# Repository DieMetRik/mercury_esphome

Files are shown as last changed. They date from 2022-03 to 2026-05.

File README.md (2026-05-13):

# Меркурий 206 <-> ESP8266 <-> Home Assistant

## Обновление от 13.05.2026

Добавлен модуль в виде external_component для совместимости с 2025.2+
Пока тестировался на 2025.11
---------------------------------------------------------------------------------

disclaimer:
Сразу скажу, что я не проф. программист, поэтому код может где то быть не элегантен.

За основу взят проект https://github.com/RocketFox2409/MercuryESPHome

И так, была задача передавать показания со счетчика Меркурий 206 (RS-485) в Home Assistant. 

Изначально провод от счетчика шел через преобразователь USB-RS485 в сервер HomeAssistant на Raspberry и через Node-Red формировался запрос и принимался ответ. Все работало, но пришло время развиваться и убрать лишние провода. 

Было собрано 3 сетапа:

1. Первый сетап: Wemos D1 mini + RS485 (MAX485 chipset) + DC-DC конвертер для стабильного питания.
   Работает, но очень не стабильно, постоянно отваливается Wemos.
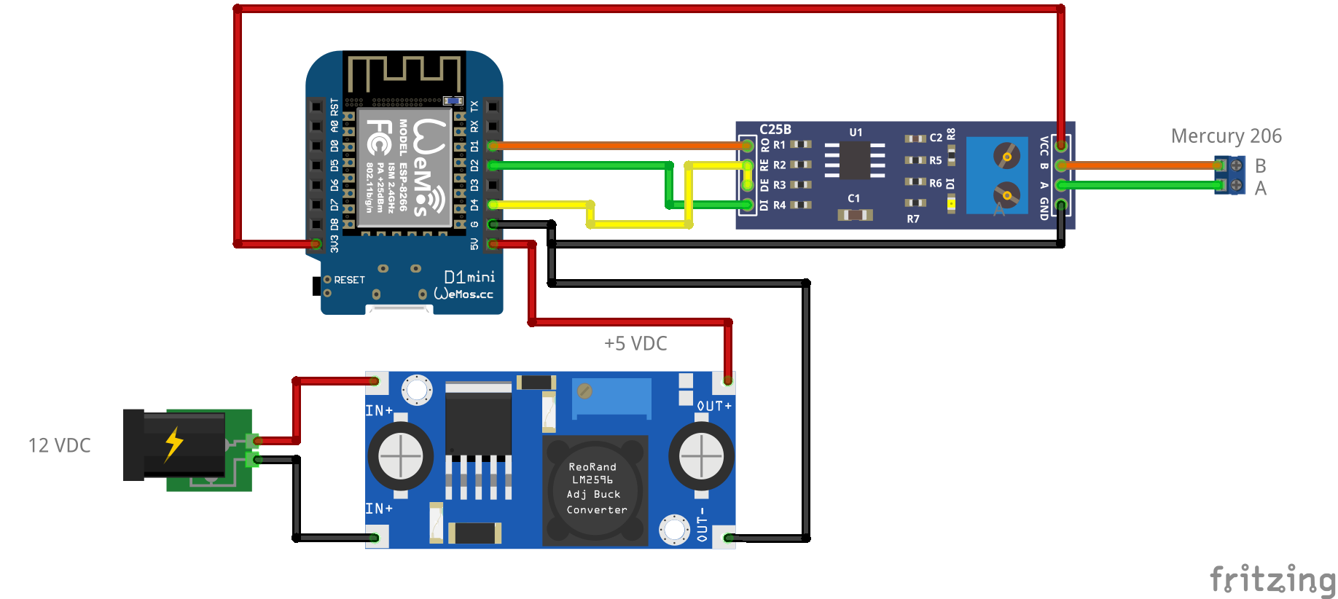
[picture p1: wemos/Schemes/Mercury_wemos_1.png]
   
2. Во втором сетапе добавил дополнительный DС-DC для питания модуля RS485
   Стало постабильнее, но все равно отваливается, так как в Wemos использовал SoftwareSerial, думаю дело в этом
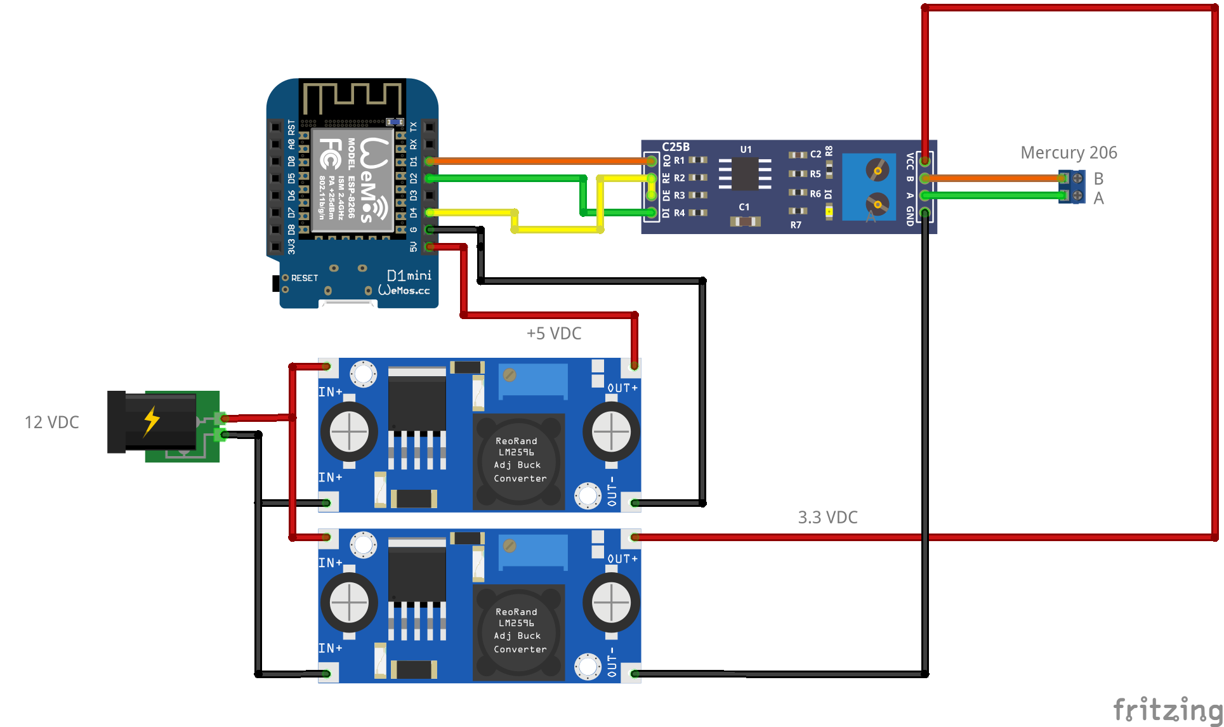
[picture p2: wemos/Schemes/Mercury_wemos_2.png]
   
3. Третий сетап аналогичен второму, только Wemos заменил на ESP-01s с HardwareSerial, работает стабильно. Больше трогать не буду.
   Если будут проблемы, можно еще попробовать Wemos с HardwareSerial (пока не изучал вопрос).
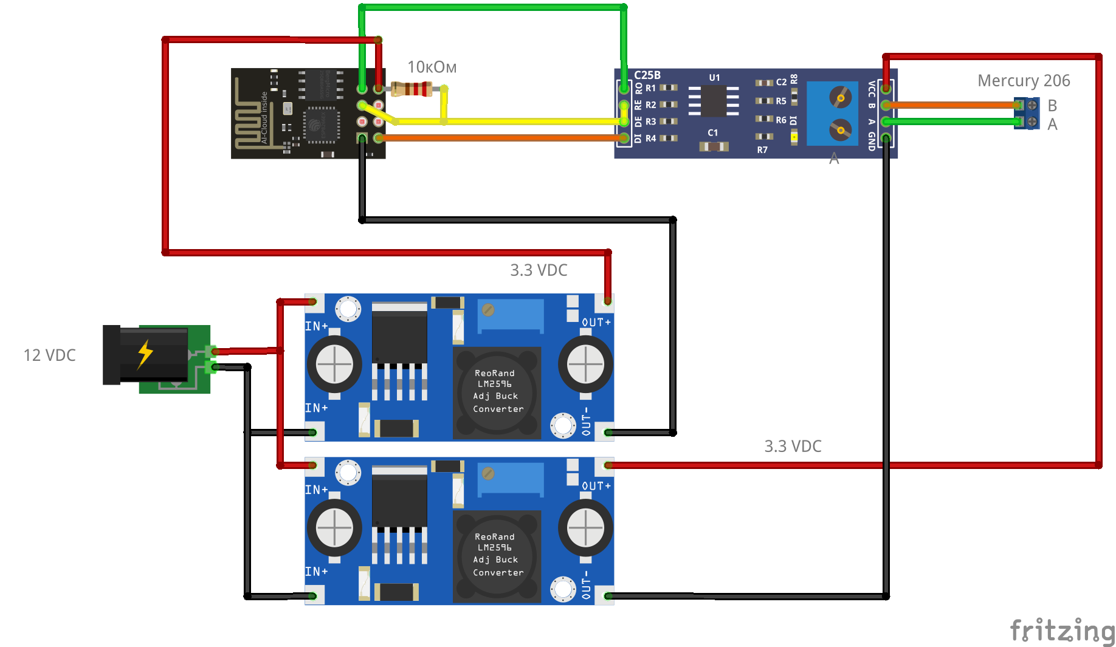
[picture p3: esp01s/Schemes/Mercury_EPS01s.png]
   
4. Купил новую плату для Modbus https://aliexpress.ru/item/32817720482.html c ней стало намного проще работать. Рекомендую именно ее.
   Там все просто:
   - 3.3 <-> VCC 
   - RX <-> RX
   - TX <-> TX
   - GND <-> GND
   В этой плате не нужно подавать дополнительно сигнал на чтение\запись, что упрощает и сборку и код
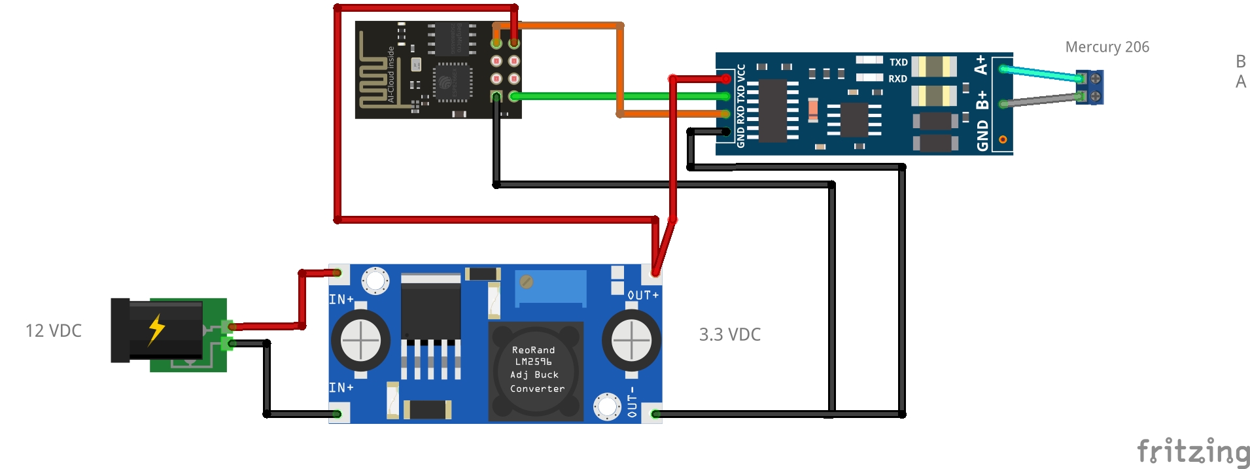
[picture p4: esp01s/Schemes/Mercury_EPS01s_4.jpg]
   
   
Для соответствующего сетапа потребуется:
Скопировать 2 файла в /config/esphome/mercury/
- mercury-200.02.h
- sensor.py

Сожержимое yaml файла скопировать в свой проект в ESPHome 
Поменять адресс счетчика в файле "mercury-200.02.h"

В Home Assistant сделал вот так:
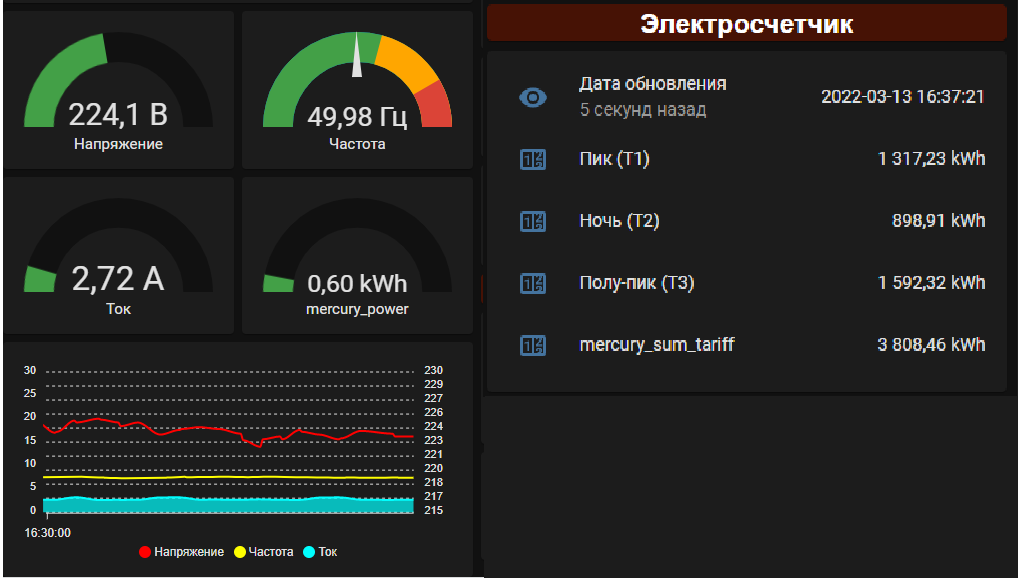
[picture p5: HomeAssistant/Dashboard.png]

Прокинул все в Energy Management и получилось вот так:
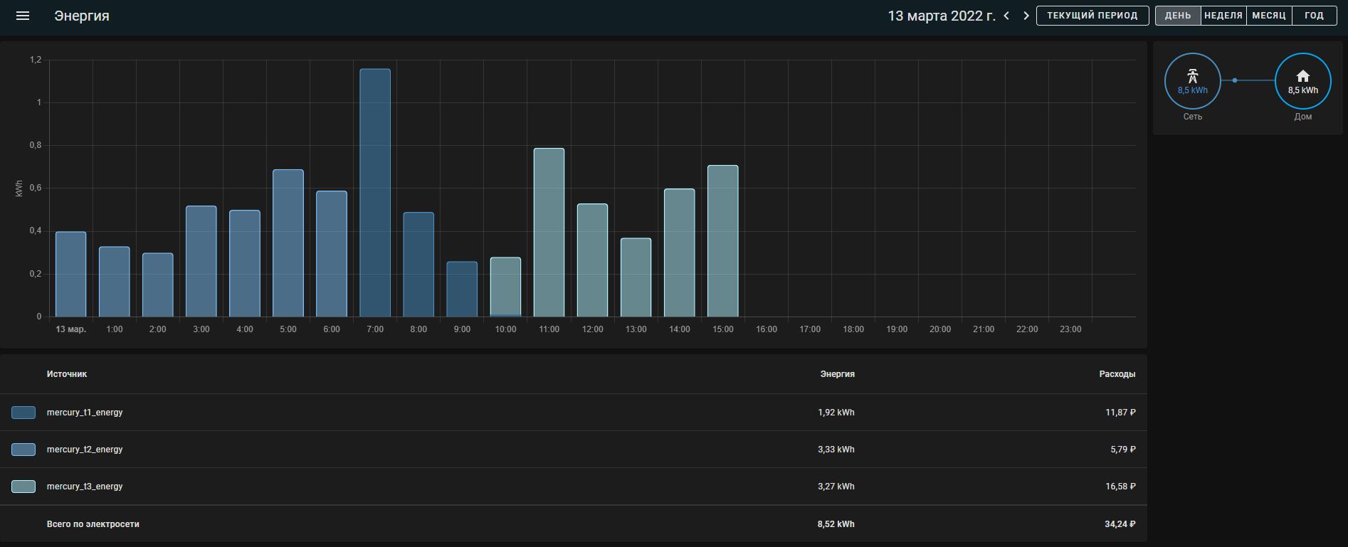
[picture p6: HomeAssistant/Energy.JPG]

Цены по тарифам взял из интеграции "Личный кабинет Интер РАО"

настроил отправку показаний в Энергосбыт через интеграцию "Личный кабинет Интер РАО" (устанавливается через HACS) + Node-Red для формирования данных.

Оборудование:

ESP01s заказывал у Win Win с Алика https://aliexpress.ru/item/2037396994.html
Для ESP01s первый раз нужен программатор, я использовал: https://aliexpress.ru/item/32688280601.html
Нужно сделать 2 перемычки:
GND + IO0
3.3V + EN
Я припаял 8 pin к программатору с другой сторны и просто сделал перемычками. Получилось универсально.

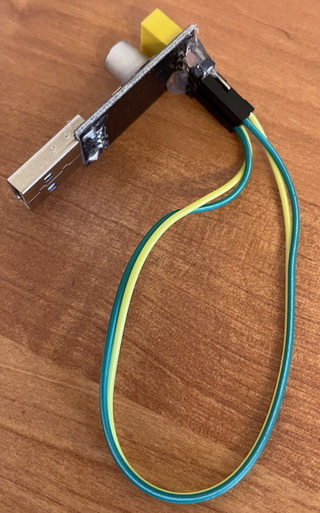
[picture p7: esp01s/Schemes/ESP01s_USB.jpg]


Wemos D1 mini V3.0.0 там же https://aliexpress.ru/item/32651747570.html

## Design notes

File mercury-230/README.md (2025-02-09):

# Меркурий 230 <-> 485 <-> ESP32 <-> Home Assistant

Автор кода https://github.com/Brokly/ESPHome-Mercury230

Я просто добавил возможность просмотра тарифов по 3м фазам Активная и Реактивная энергия.

Все что вы делаете, вы делаете на свой страх и риск. 

Вы должны понимать, что вы делаете и к чему это может привести.

Автор скриншотов: https://github.com/BoskSpb



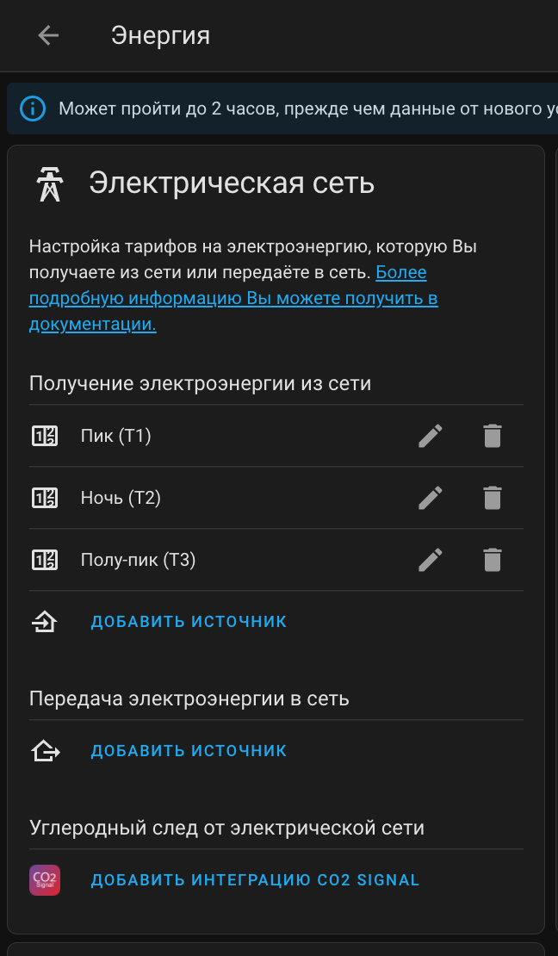
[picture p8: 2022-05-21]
HomeAssistant/Energy_1.png

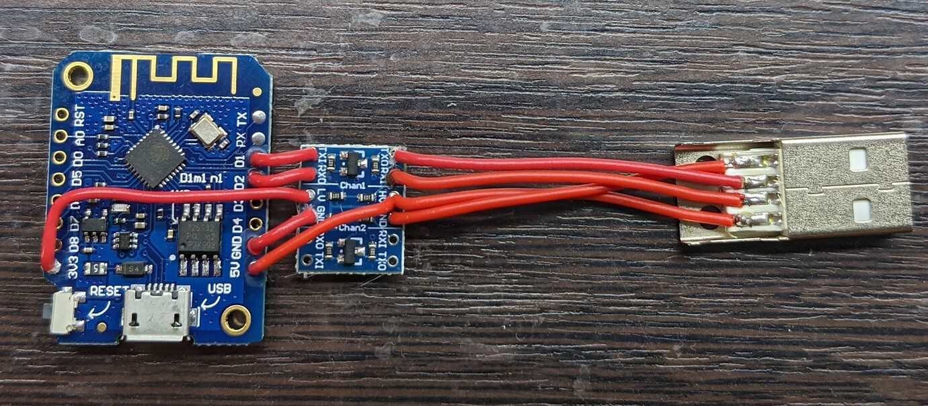
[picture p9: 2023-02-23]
wemos/Schemes/Level.png

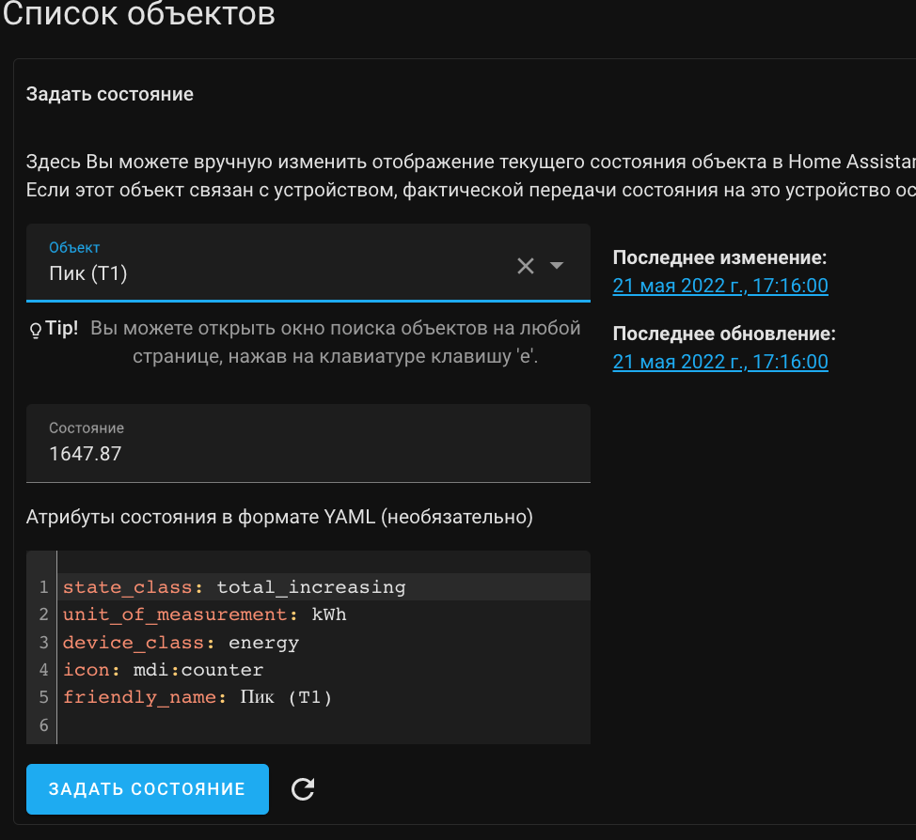
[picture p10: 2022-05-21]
HomeAssistant/Energy_4.png

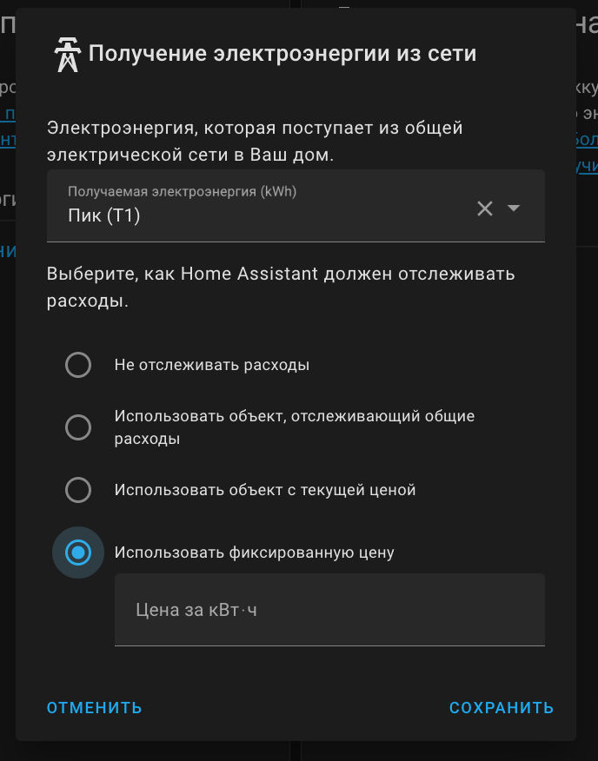
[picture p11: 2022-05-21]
HomeAssistant/Energy_3.png

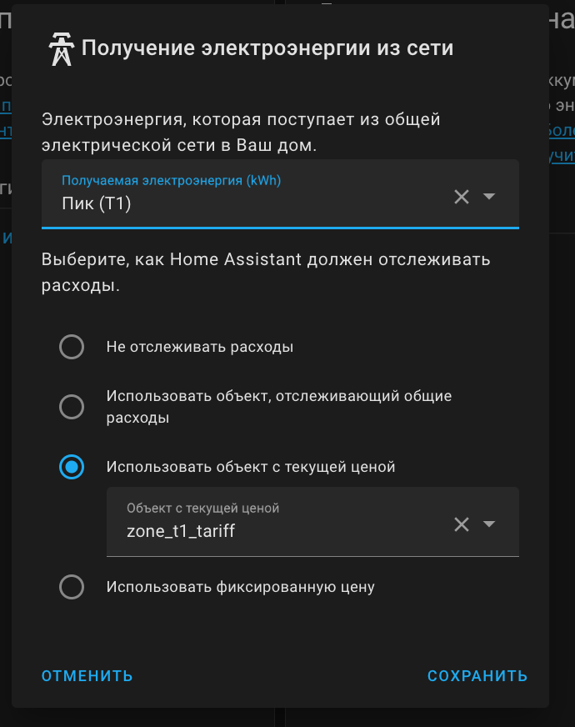
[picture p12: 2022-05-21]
HomeAssistant/Energy_2.png

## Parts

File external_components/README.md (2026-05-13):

# Меркурий 206 <-> ESP32 ethernet <-> Home Assistant
disclaimer:
Сразу скажу, что я не проф. программист, поэтому код может где то быть не элегантен.

За основу взят проект https://github.com/RocketFox2409/MercuryESPHome

Переделал проект из  custom_component --> external_component

Плата ESP32 с Ethernet на борту, самый стабильный вариант!

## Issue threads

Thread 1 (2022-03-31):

Прошу помощи.

meta11st87, 2022-03-31:
Приветствую. Спасибо за инфу по подключению.
Пытаюсь повторить ваше проект, но маленько на другом железе и ничего не выходит(

Использую плату nodemcu esp32(потому что была в наличии) и плату ttl rs485, вроде как называется XY-017
Управление потоком аппаратное, поэтому вроде как не нужно ничего на плату подключать, кроме rt/tx и питания.
Схема подключения:
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

Конфиг до раздела сенсоров:
```
esphome:
  name: mercury
  includes:
    - /config/esphome/mercury/mercury-200.02.h #Указываем свой путь до файла

esp32:
  board: nodemcu-32s
  framework:
    type: arduino

# Enable logging
logger:

# Enable Home Assistant API
api:
  password: !secret ha_password

ota:
  password: !secret ota_password

wifi:
  ssid: !secret wifi_ssid
  password: !secret wifi_password

  # Optional manual IP
  manual_ip:
    static_ip: 192.168.1.150
    gateway: 192.168.1.1
    subnet: 255.255.255.0

  # Enable fallback hotspot (captive portal) in case wifi connection fails
  ap:
    ssid: "mercury-206"
    password: !secret ap_password

captive_portal:

uart:
  id: uart_bus
  tx_pin: 17
  rx_pin: 16
  baud_rate: 9600
```

Тх моргают, но счётчик не отвечает, рх молчит. Плату запитывал тестово от повербанка.
Собственно, ряд вопросов:
У вас какой модификации счётчик? У меня RN, вроде как они отличаются, что какому-то счётчику нужно доппитание, а какому-то нет.

Адрес счётчика как правильно выставить? У меня номер счётчика 12343320 -18. Если ставлю 320 то результата положительного нет. Вроде как эти счётчики должны на 0 адрес отвечать, если в шине он один, но это тоже не работает.

Вроде все варианты уже перепробовал, но не взлетает.

Может у вас есть мысли ЧЯДНТ?

upd. Пробовал на контакты счётчика, которые рядом с rs расположены, и которые промаркированы как U и земля, подать 5в, судя по той инфе, которая нашлась в интернете это питание rs-интерфейса - не помогло.

DieMetRik, 2022-04-01:
Для начала.
Счётчик новый?
В него могли записать другой адрес?

У меня просто в счётчик местный энергосбыт записал номер квартиры как адрес счётчика. Поэтому там указано 319. Хотя по факту там должен был быть его серийный номер без нолей вначале и без тире в конце. Если в ваш счётчик никто не залезал, кроме Вас, то в поле адреса нужно вписать: 12343320

Пробовали менять провода А и В местами?

Есть ли у Вас преобразователь USB-RS485? Стоил раньше в районе 100р +-
С ним диагностика вопроса была бы намного проще.

Можно было бы подключится к счётчику прям с ноутбука и проверить, есть ли вообще связь. Есть специальная программа для счётчиков Меркурий от самого Маркурия.

Перед всей своей эпопеей со счётчиком, я сначала подключился ей и проверил, что счётчик отзывается.
Потом уже подключался с помощью ESP

Ещё можно поиграться с временем delay вот в этой части кода:

```
		digitalWrite(0, HIGH);
		write_array(command, 7);
		delay(12);
		digitalWrite(0, LOW);
		//delay(13);
```

В Вашем случаи вообще нужно будет закоментить: digitalWrite(0, HIGH); digitalWrite(0, LOW); так как у Вас нормальный преобразователь. А с delay можно поиграться.

У меня было такое что, при малом delay порт ESP не успевал передать все данные и данные уходили урезанные.

Все это я диагностировал с помощью USB to RS485 преобразователя. С него же и подключался к счётчику через ноут.
`https://aliexpress.ru/item/1005003203376943.html?`

Если у Вас счётчик без буковки S, то ему нужно внешнее питание +5V.  при этом GND я так понял должны быть соединены. Опять же это не точно. Нужно смотреть схему подключения.

DJTerentjev, 2022-04-01:
У китайских плат часто перепутано RX и TX, но если TX моргает значит, вроде правильно. Похоже у вас адрес счётчика неправильно указан. Я когда подключал, сначала подключался к счётчику утилитой Меркурия через переходник RS-485-USB.  Номер по умолчанию, должен быть указан в мануале. Если правильно помню, должен быть 80 или 64 (перевести в hex).

DieMetRik, 2022-04-01:
Надо смотреть какой Меркурий. Там для разных меркуриев и по разному задаёте адрес. Для 206 это серийник

meta11st87, 2022-04-01:
>
Благодарю за ответ.
Счётчику год, похоже, надо сначала usb -> rs485 опросить, может действительно поменян адрес.
Жаль что по месту их не найти в городе.

Но и адрес правильно я не указал(пробовал по разному, хотя мне вообще казалось что в таких устройствах адрес не может быть больше 255), может ночью потестирую ещё.

А В не менял местами, вроде судя по описанию интерфейса rs485 они должны подключаться напрямую.

С delay эксперементировать в сторону увеличения, я правильно понял?

meta11st87, 2022-04-01:
> У китайских плат часто перепутано RX и TX. Я использую XY-017 и подключаю TX к TX, RX к RX. Если TX моргает значит, вроде правильно. Похоже у вас адрес счётчика неправильно указан. Я когда подключал, сначала подключался к счётчику утилитой Меркурия через переходник RS-485-USB. Номер по умолчанию, должен быть указан в мануале. Если правильно помню, должен быть 80 или 64 (перевести в hex).

Да, я видел эту инфу в интернете, пробовал tx rx менять местами.
В итоге пришёл к тому, что если моргает tx, значит подключение правильное в этой части схемы.

DieMetRik, 2022-04-01:
Это не модбас. Поэтому адрес может быть любой. Выводы A и B каждый по разному может делать. Так что тут только поменять и попробовать.
Делай увеличить надо попробовать.

AntoxaSa, 2022-04-29:
Добрый день!
Хочу тоже счет прокинуть в HA.
Встал выбор какой лучше купить меркурий 200.02 или 206? чем они отличаются?

DieMetRik, 2022-04-29:
Добрый день!
200.02 не имеет RS-485 интерфейса
Для 206 есть RS-485. У меня Меркурий 206 PRSN Отлично справляется со своими делами

AntoxaSa, 2022-04-29:
а принципиальная разница какая? 200 же вроде с кан и так же прокидывается в HA ?

AntoxaSa, 2022-04-29:
Заказал как у Вас счетчик,нашел за адекватную цену. 206 PRSN.Подскажите еще где покупали преобразователь TTL RS485 и какой

DieMetRik, 2022-05-08:
Купил новую плату для Modbus https://aliexpress.ru/item/32817720482.html c ней стало намного проще работать. Рекомендую именно ее.
   Там все просто:
   - 3.3 <-> VCC
   - RX <-> RX
   - TX <-> TX
   - GND <-> GND

AntoxaSa, 2022-05-09:
> DieMetRik

а для этой платы Modbus https://aliexpress.ru/item/32817720482.html  в коде Вашей программы что то менять нужно?

DieMetRik, 2022-05-09:
По большому счету нет. Можно закоментировать все строки:
191, 192, 199, 201, 202
А можно и не комментировать. На работоспособность ни как не влияют

vickkz, 2022-05-14:
День добрый,тоже такая же кака,пробовал и таким и таким конвертером, тх моргает, через юсб в РС 485 меркуриевской прогой цепляется нормально и подключается,а через есп не хотит( делей увеличивал, тоже самое,а какой прогой вы диагностировали проблемы и опрашивали счётчик?

DieMetRik, 2022-05-14:
Адрес правильно выставили? Там вместо 319 нужно выставить тот. Который вы выставляли в проге Меркурия.

Попробуйте поменять A и B провода местами.

Если это не поможет. Напишите. Я скажу как диагностировал запросы.

AntoxaSa, 2022-05-18:
Собрал устройство.Прошил, Моргает TX на плате и все но счетчик данные не передает.В Home Asisstent пишет неизвестные данные.A и B перекидывал местами.  Оригинальный серийный номер счетчика состоит из 8 цифр может в этом проблема? Попробовал через USB RS485 и программу конфигуратор все работает. Есть мысли?

AntoxaSa, 2022-05-18:
Вообщем разобрался.Если в счетчике серийный номер из 8 цифр то программа не работает.Видать не может пересчитать серийный номер правильно конвертор.Меняем в счетчике серийный номер на 6 цифр и вауля все работает! HA видит счетчик

vickkz, 2022-05-19:
Спасибо автору за консультацию,тоже удалось завести счётчик через есп,пришлось подредактировать код и стартовый байт поменять в строке запроса авторизации и в строках запроса,потом блудняк был когда рх и тх подключал непосредственно к есп,не работал рх,потом подключил как в скетче и все пошло моргать

meta11st87, 2022-05-19:
.

> есп,пришлось подредактировать код

Выложите свою версию для людей, пожалуйста. И какой счётчик использовали, его конфигурацию(P,R,S,N)

Я всё до дому никак не доеду, чтоб свой счётчик потестировать

vickkz, 2022-05-19:
Счётчик 206 PR без собственного питания,подал 12 в от внешнего источника питания,номер счётчика надо перевести в шеснадцатиричном систему из десятичной,проверил через USB -rs485 правильно ли есп посылает запрос авторизации.

AntoxaSa, 2022-05-19:
> Спасибо автору за консультацию,тоже удалось завести счётчик через есп,пришлось подредактировать код и стартовый байт поменять в строке запроса авторизации и в строках запроса,потом блудняк был когда рх и тх подключал непосредственно к есп,не работал рх,потом подключил как в скетче и все пошло моргать

Выложите код, тоже интересно. для чего правили.

AntoxaSa, 2022-05-19:
> Счётчик 206 PR без собственного питания,подал 12 в от внешнего источника питания,номер счётчика надо перевести в шеснадцатиричном систему из десятичной,проверил через USB -rs485 правильно ли есп посылает запрос авторизации.

не очень понял, для чего переводить? вроде конвертор встроенный в код уже

meta11st87, 2022-05-19:
Итак. Спустя столько времени добрался до счётчика.
Похоже, совет про "сменить номер счётчика" работает с 206rn.
Usb<->RS485 у меня не было, поэтому я взял обычный ttl конвертер для прошивки esp, соединил его с тем самым модулем, через который я пытался опросить счётчик:
rx->rx
tx->tx
vcc->vcc
gnd->gnd,
Вбил номер счётчика по паспорту и сразу же считал данные с него.
Сменил адрес на трёхзначный, опросил уже по новому адресу и проверил что адрес сменился.

А далее всё как в доке написано, сразу заработало.

Но. Я не увидел данные по тариф 1, тариф 2. Правда опрашивал я его через esp не долго, буквально минуту, ибо теперь надо согласовать подключение этой штуки с УК, без электрика наверно не стоит такое делать, счётчик в общем коридоре.
Скрин данных, которые я успел получить. Может данные по тарифам подтягиваются не сразу а раз в определённое время?

А,нет. Скрина не будет. Не знаю как тут картинку запостить. Рукалицо.

vickkz, 2022-05-19:
> Выложите код, тоже интересно. для чего правили.
ну в общем с начальным кодом было так, номер счетчика неверно передавался за счет того,что в коде жестко прописаны стартовые байты 00, а чтобы мой счётчик завелся нужно было 02
пришлось поменять в строках отвечающих за авторизации и за передачу данных 00 на 02
`	void calculateParams(unsigned char *frame, uint32_t serial_, unsigned char comm)
	{
		frame[0] = 0x02;
		frame[1] = serial_ >> 16;
		frame[2] = serial_ >> 8;
		frame[3] = serial_;`
<a href="https://yapx.ru/v/SB25z" title="Фотография загружена на фотохостинг yapx.ru">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</a>

DieMetRik, 2022-05-19:
Всем привет. Сегодня попробую наваять правильный код для 8 цифр серийного номера.
Пока не правильно рассчитываться CRC сумма. Но думаю добью.

Тарифы получаются не сразу...У них период обновления около 10 минут... + еще время на корректное CRC при получении пакета. Иногда требуется 3-4 часпроса.

DieMetRik, 2022-05-20:
Я поправил...Если кто сможет протестировать с длиной серийного номера 8 цифр

AntoxaSa, 2022-05-20:
> Я поправил...Если кто сможет протестировать с длиной серийного номера 8 цифр
Протестирую сегодня.

DieMetRik, 2022-05-21:
Подкорректировал код. Проверьте пожалуйста. Сейчас входные сообщения должны прилетать в HA

AntoxaSa, 2022-05-21:
> Подкорректировал код. Проверьте пожалуйста. Сейчас входные сообщения должны прилетать в HA

Все отлично работает! Еще вопрос а что за сенсор mercury_crc который пишет неизвестно ?
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

DieMetRik, 2022-05-21:
Это когда то был сенсор отладночный. Надо бы его удалить. А так пока просто деактивировать

meta11st87, 2022-05-22:
Раз у всех всё получилось и заработало, предлагаю:

Во-первых, автору прошивки закрыть этот ишью.

Во-вторых, всех кто воспользовался кодом насыпать автору звёзд в репу и задонатить.

Closed 2022-05-22.

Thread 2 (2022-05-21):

Небольшой вопрос

drronn, 2022-05-21:
Здравствуйте! Занимался подключением счетчика меркурий 200.02 и все закончилось успешно, но на Вашей странице увидел скриншот с пробросом в Energy Management. Не подскажете как Вы это сделали? Сорри если оффтоп - просто на гитхабе нельзя отправлять сообщения в приват. Спасибо!

DieMetRik, 2022-05-21:
Добрый день. Заходите на сервер умного дома. Далее /config/energy
Там добавляете сенсоры с kWh и фиксированную цену за kWh.

Скриншоты в папке /HomeAssistant

DieMetRik, 2022-05-21:
Если все получится. Напишите, я закрою

drronn, 2022-05-22:
Здравствуйте. Посмотрел, /config/energy - такой папки не было. Создал. Я правильно понимаю что в этой папке нужно создать yaml файл и записать туда что то вроде:
template:
  sensor:
    - name: "T1"
      unit_of_measurement: 'kWh'
      device_class: energy
      state_class: measurement
      state: '{{ states.sensor.tariff1.state }}'

?

DieMetRik, 2022-05-22:
Не не. Откройте в браузере. http://[адрес home assistan]/config/energy

DieMetRik, 2022-05-22:
Либо через:
Настройки->панели->Энергия

drronn, 2022-05-22:
Я вывел предварительно пункт энергия в боковую панель, но беда в том что там просто невозможно ничего добавить(на скриншоте) поэтому и подумал надо создавать папку и писать.
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.

Если выбрать использовать фиксированную цену и написать 1 то он также не дает сохранять.

DieMetRik, 2022-05-22:
Вверху нужно выбрать показаня со счетчика kWh

DieMetRik, 2022-05-22:
Покажите мне ваши счетчик
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

DieMetRik, 2022-05-22:
Покажите мне ваши счетчик

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

drronn, 2022-05-22:
А вот дело в том что в верхнем раскрывающемся меню ничего нет. То есть нельзя ничего выбрать.
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
А вообще пока вся конструкция пока выглядит вот так
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
если я Вас правильно понял.
В панели разработчика вот так
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

drronn, 2022-05-22:
После того как отправил понял - надо в атрибуты попробовать дописать чтобы стало как у Вас. Возможно это поможет.

DieMetRik, 2022-05-22:
Да...Именно
Нужно обязательно добавить:
    unit_of_measurement: "kWh"
    device_class: energy
    state_class: total_increasing

drronn, 2022-05-22:
Супер! Все получилось! Тему можно закрывать! Спасибо!

Closed 2022-05-22.

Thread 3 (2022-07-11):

На трёх фазный Меркурий (230-236) можете сделать?

sergeibush, 2022-07-11:

DieMetRik, 2022-07-13:
Добрый день!

Думаю да. Напишите какие данные по 3х фазной сети нужны.

and7ey, 2024-01-24:
Добрый день, меня тоже интересует трехфазный Меркурий. У меня 236 ART-01 PQRS.
Показаний и напряжения на каждой фазе, кажется, должно хватить.

https://wifi-iot.com/p/wiki/238/ru/ - тут есть некое решение, но оно вроде в HA не добавляется.

kirush0280, 2025-02-23:
Тоже интересно, мучаюсь с 236 ART-02 PQRS

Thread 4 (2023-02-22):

Пару вопросов по Меркурий 206

DaN66O, 2023-02-22:
Добрый день.
1. Почему вы пишете что использовали SoftwareSerial на Wemos D1 mini, вроде у вас на картинке есть RX и TX ?
2. Вы устанавливали сопротивление 120 Ом между контактами А и В на счетчике ?
В документации по RS485 пишут :
_По стандарту RS-485 шина должна быть проложена без ответвлений и на концах линии должны
быть терминирующие резисторы (100-120 Ом)._
3. Можно ли плату Modbus питать от 5в ?

DieMetRik, 2023-02-23:
Добрый!
1. С Hardware Serial на Wemos D1 mini не завелось, даже при проставление:
logger:
  baud_rate: 0
Не знаю в чем причина, с Software Serial ESP падала часто, стабильно раз в 2-3 часа перезагружалась.
И это не только со счетчиком, у меня еще стоят кондиционеры с ESP, так вот на одном стояло Hardware, а на втором Software. И вот Software падал...

2. Да, со стороны счетчика.
3. Можно при использовании Шифтера.
4. Это нужно собирать на ESP32. Самый стабильный вариант.

У ESP32 есть 2 Hardware Serial и сейчас у меня собрано именно так.

Стоит ESP32 + Shifter + Uart to 485
Shifter:
https://aliexpress.ru/item/32247463702.html?spm=a2g2w.orderdetail.0.0.78f04aa6T0iH3a&sku_id=12000018838496503
Аккуратно, там 10шт в комплекте...я случайно заказа 30шт так.
Вот пример как подключается Level Shifter:
 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
Тут правда D1 Mini, но на ESP32 тоже самое.

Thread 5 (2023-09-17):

Как выяснить адрес счетчика?

Spirituss, 2023-09-17:
ПОдскажите, как узнать адрес счетчика, который нужно прописать в *.h?
Это серийник или код из модбаса?

DieMetRik, 2023-09-17:
Если никто не вмешивался в счетчик. То последние цифры серийника

Spirituss, 2023-09-17:
Серийник на самом счетчике написан?

DieMetRik, 2023-09-17:
Да

Closed 2023-11-27.

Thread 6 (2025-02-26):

Несколько счетчиков 23*

kirush0280, 2025-02-26:
Добрый день!
А можно как то снимать показания с нескольких счетчиков? Вроде библиотека не предназначена для этого, можете помочь с доработкой?

DieMetRik, 2025-02-26:
Он с одного то снимает с ошибками, а если добавить больше, я боюсь ему конкретно поплохеет

DieMetRik, 2025-02-26:
Цена комплекта на 1 счетчик менее 1000р

kirush0280, 2025-02-26:
Спасибо я вроде реализовал на базе https://github.com/flystyle/Mercury230, пришлось править - мне нужно с 4 снимать, если с одного плохо снимает, какой смысл в 4 комплектах?
Пришлось логику переписать, добавил:
$addresses = [49,50,51,52];
и долблю их по очереди - до тех пор, пока не получу от всех ответ. Если ответа нет после 5 запросов - пропускаем.

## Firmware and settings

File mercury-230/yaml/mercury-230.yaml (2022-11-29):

#Автор кода https://github.com/Brokly/ESPHome-Mercury230
#My telegram https://t.me/DieMetRik

# Подключение ног ESP32
# 
# Обязательный элемент
#  ModBus adapter  https://esphome.io/_images/rs485.jpg
#    tx_pin: GPIO14
#    rx_pin: GPIO27
# Дополнительные элементы, для работы не нужны
#  Led Red:   gpio4
#  Led Blue:  gpio16
#  Button:    gpio32
#  Relay:     gpio13

# Имя устройства
substitutions:
  devicename: mercury-230
  upper_devicename: Mercury-230
  location: В электрощите. # место установки
  device_ip: 192.168.1.132


external_components:
  - source: 
      type: local
      path: my_components     
    components: [ energy_meter_mercury230 ]
    refresh: 0s

esphome:
  name: $devicename
  includes:
    - my_components/energy_meter_mercury230/energy_meter_mercury230.h
    - my_components/energy_meter_mercury230/mercury230_proto.h
  on_boot:
    priority: 600
    then:
       - script.execute: script_show_text

esp32:
  board: esp32dev
  framework:
    type: arduino

wifi:
  ssid: !secret wifi_ssid
  password: !secret wifi_password
  manual_ip:
    static_ip: ${device_ip}
    subnet: !secret wifi_subnet
    gateway: !secret wifi_gateway


  ap:
    ssid:  ${upper_devicename} Hotspot
    password: !secret ap_password

captive_portal:

debug:

logger:
  level: ERROR
  #level: DEBUG
  #baud_rate: 0

api:
#    password: !secret api_pass

ota:
    password: !secret ota_password

web_server:
  port: 80
  auth:
    username: !secret web_server_login
    password: !secret web_server_password

uart:
  id: uart_bus
  tx_pin: GPIO14
  rx_pin: GPIO27
  baud_rate: 9600
  data_bits: 8
  parity: NONE
  stop_bits: 1

binary_sensor:
#статус устройства
  - platform: status
    name: ${upper_devicename} HA Connected
# кнопка
  - platform: gpio
    pin:
      number: GPIO32
    name: $upper_devicename Button
    internal: true
    on_click:
# переключить реле при коротком нажатии   
      - min_length: 10ms
        max_length: 1000ms
        then:
          - switch.toggle: relay_sw
# restart esp , нужно зажать кнопку на 5000 секунд (ПОСЧИТАТЬ ДО 8)
      - min_length: 4000ms
        max_length: 6000ms
        then:
          - switch.toggle: restart_sw_id

output:
  - platform: ledc
    id: red_led
    pin:
      number: GPIO4
      inverted: False

light:
  - platform: monochromatic
    output: red_led
    id: relay_led
    default_transition_length: 1ms 
# для управления и индикации статуса
# эта же нога используется для мигания при чтении ModBus
  - platform: status_led
    id: blue_led
    internal: true
    pin: GPIO16  
    
switch:
#свитч рестарта устройства
  - platform: restart
    name: ${upper_devicename} Restart SW
    id: restart_sw_id
# реле
  - platform: gpio
    id: relay
    pin: GPIO13
#виртуальная кнопка, совмещает реле и диод
  - platform: template
    restore_state: true
    name: $upper_devicename Relay
    optimistic: true
    id: relay_sw
    internal: false
    turn_on_action:
    - switch.turn_on: relay
    - light.turn_on: relay_led
    turn_off_action:
    - switch.turn_off: relay
    - light.turn_off: relay_led
#виртуальная кнопка, для скрытия длинного текста
  - platform: template
    name: $upper_devicename Hide Notes
    optimistic: true
    id: hide_notes
    entity_category: config
    icon: 'mdi:eye-off'
    turn_on_action:
      - script.execute: script_hide_text
    turn_off_action:
      - script.execute: script_show_text
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

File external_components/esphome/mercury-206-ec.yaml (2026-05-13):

substitutions:
  device_name: "mercury-206-es"
  device_ip: 192.168.1.XXX
  device_description: "Мониторинг эл. счетчика Меркурий"
  board: esp32dev
  platform: esp32
  type: arduino

esphome:
  name: ${device_name}
  name_add_mac_suffix: false
  comment: ${device_description}

${platform}:
  board: ${board}
  framework:
    type: ${type}

# Подключаем локальную папку с компонентами
external_components:
  - source: 
      type: local
      path: my_components
# Настройка логирования и API
logger:
  level: debug

ota:
- platform: esphome  
  password: !secret ota_password

api:
  encryption:
    key: !secret encryption_key

ethernet:
  type: LAN8720
  mdc_pin: GPIO23
  mdio_pin: GPIO18
  clk:
    pin: GPIO0
    mode: CLK_EXT_IN

  phy_addr: 1
  power_pin: GPIO16

  manual_ip: 
    static_ip: ${device_ip}
    gateway: !secret wifi_gateway
    subnet: !secret wifi_subnet

web_server:
  port: 80
  include_internal: true
  auth:
    username: !secret web_server_login
    password: !secret web_server_password
debug:
  update_interval: 5s

uart:
  id: uart_bus
  tx_pin: GPIO17
  rx_pin: GPIO5
  baud_rate: 9600

# Инициализируем основной контроллер
mercury:
  id: my_meter
  update_interval: 500ms
  # Здесь можно добавить серийный номер если вынести его в конфиг
  serial_number: XXXXXX

# Подключаем сенсоры к контроллеру
sensor:
  - platform: mercury
    voltage:
      name: "mercury_voltage"
      device_class: voltage
      state_class: measurement
      icon: "mdi:alpha-v-circle-outline"
      unit_of_measurement: "V"
      accuracy_decimals: 1

    current:
      name: "mercury_current"
      device_class: current
      state_class: measurement
      icon: "mdi:alpha-a-circle-outline"
      unit_of_measurement: "A"
      accuracy_decimals: 2

    power:
      name: "mercury_power"
      device_class: power
      state_class: measurement
      icon: "mdi:alpha-p-circle-outline"
      unit_of_measurement: "W"
      accuracy_decimals: 0

    t1:
      name: "mercury_t1_energy"
      icon: "mdi:counter"
      unit_of_measurement: "kWh"
      accuracy_decimals: 2
      device_class: energy
      state_class: total_increasing

    t2:
      name: "mercury_t2_energy"
      icon: "mdi:counter"
      unit_of_measurement: "kWh"
      accuracy_decimals: 2
      device_class: energy
      state_class: total_increasing


    t3:
      name: "mercury_t3_energy"
      icon: "mdi:counter"
      unit_of_measurement: "kWh"
      accuracy_decimals: 2
      device_class: energy
      state_class: total_increasing
      
    total:
      name: "mercury_sum_tariff"
      icon: "mdi:counter"
      unit_of_measurement: "kWh"
      accuracy_decimals: 2

    frequency:
      name: "mercury_frequency"
      icon: "mdi:sine-wave"
      device_class: frequency
      state_class: measurement
      unit_of_measurement: "Hz"
      accuracy_decimals: 2

  - platform: debug
    free:
      name: "Heap Free"
    block:
      name: "Heap Max Block"
    loop_time:
      name: "Loop Time"


#Uptime - показывает сколько устройство работает в сети. Тоже нужно было для отпладки.
  - platform: uptime
    name: ${device_name} uptime
    id: uptime_sensor
    internal: true
    on_raw_value:
      then:
        - text_sensor.template.publish:
            id: uptime_human
            state: !lambda |-
              int seconds = round(id(uptime_sensor).get_raw_state());
              int days = seconds / (24 * 3600);
              seconds = seconds % (24 * 3600);
              int hours = seconds / 3600;
              seconds = seconds % 3600;
              int minutes = seconds /  60;
              seconds = seconds % 60;
              return (
                (days ? to_string(days) + "d " : "") +
                (hours ? to_string(hours) + "h " : "") +
                (minutes ? to_string(minutes) + "m " : "") +
                (to_string(seconds) + "s")
              ).c_str();

text_sensor:
  - platform: mercury
    datetime:
      name: "mercury_datetime"
  - platform: version
    name: ${device_name} version
    hide_timestamp: true

  - platform: template
    name: ${device_name} uptime
    id: uptime_human
    icon: mdi:clock-start

  - platform: debug
    reset_reason:
      name: "Reset Reason"

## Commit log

2022-03-20 Update mercury-200.02.h
    Переписал опросы и чтение. Теперь тарифы опрашиваются раз в 10 минут, а ток и напряжение раз в 1.
2022-05-08 Новая плата для modbus
    Собрал четвертый сетап. Пункт 4
2022-05-09 Update README.md
    Добавил схему
2022-05-20 CRC + Длина серийного номера
    Длина серийника теперь может быть 8 цифр
2022-05-21 Поправил проверку приходящих сообщений
2026-05-13 update yaml sensors
